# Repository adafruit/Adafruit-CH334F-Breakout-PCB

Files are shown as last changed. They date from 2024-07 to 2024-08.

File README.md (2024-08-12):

## Adafruit CH334F Mini USB Hub Breakouts PCB

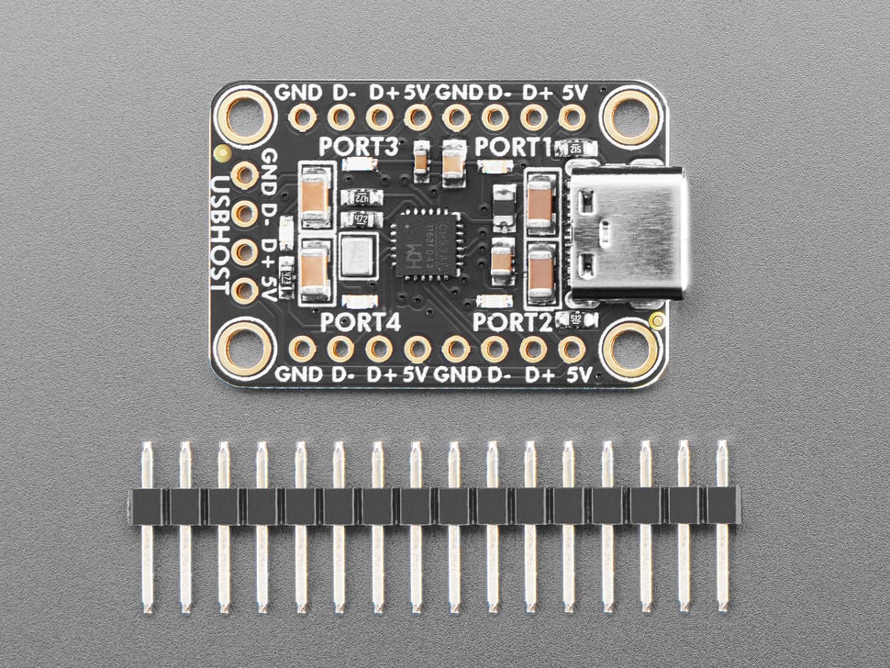
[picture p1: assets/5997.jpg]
<a href="http://www.adafruit.com/products/5997"><br/>
Click here to purchase one from the Adafruit shop</a>
<br>
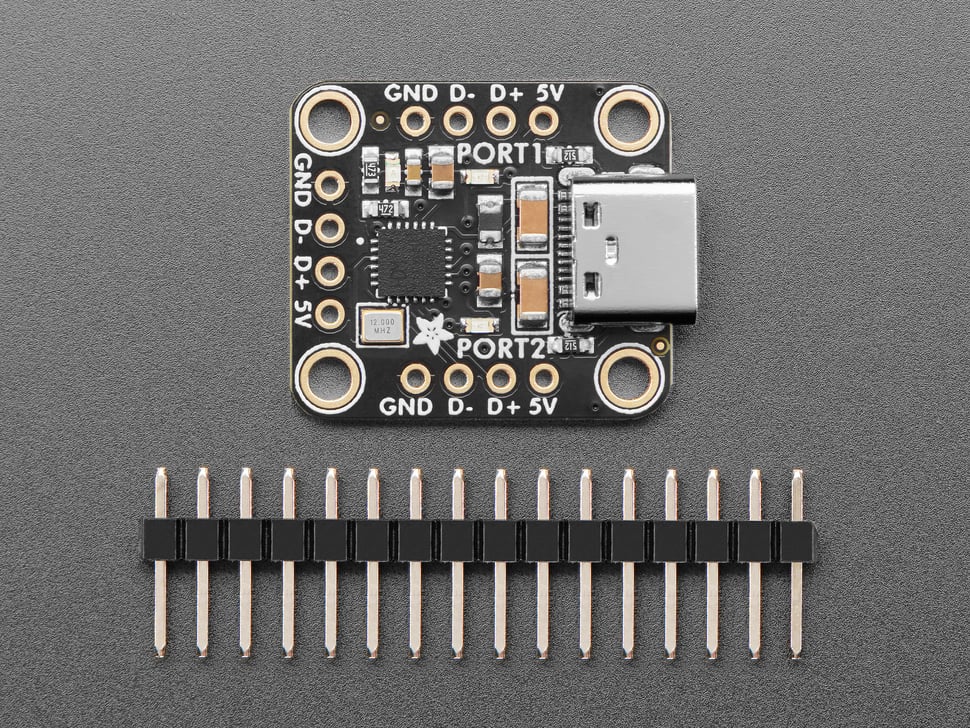
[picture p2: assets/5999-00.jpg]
<a href="http://www.adafruit.com/products/5999"><br/>
Click here to purchase one from the Adafruit shop</a>

PCB files for the Adafruit CH334F Mini USB Hub Breakouts

Format is EagleCAD schematic and board layout
* https://www.adafruit.com/product/5997
* https://www.adafruit.com/product/5999

### Description

Sometimes you've got something with USB host, like a embedded linux board, and you want to connect more than one thing. Or maybe you want to turn something like a keyboard into a multi-device USB peripheral. The Adafruit CH334F Mini 4-Port USB Hub Breakout will do that for you! it features a CH334F USB 2.1 hub chip which converts one high-speed port into four.

Most folks who use a USB hub get one that comes in an enclosure with connectors or cables included. But, those hubs are going to be bulky - they're meant for external use. This breakout board is designed to be compact, so it can easily be embedded into an enclosure or existing device. There's four mounting holes but other than that, we tried to keep it as compact as possible.

Part of how we kept it small is not including downstream ports! The breakout has either 0.1" header or USB C for the upstream, and then four 4-pin ports for peripheral connections. We expect folks to solder directly to the pads or use our 'simple' USB-breakout cables.

You get one fully assembled/tested boards and some extra header if you happen to want to plug it into a breadboard. Other than that, just keep in mind there's no USB ports for the 4 downstreams - if you need those take a look at some of the other hubs we stock.

### License

Adafruit invests time and resources providing this open source design, please support Adafruit and open-source hardware by purchasing products from [Adafruit](https://www.adafruit.com)!

Designed by Limor Fried/Ladyada for Adafruit Industries.

Creative Commons Attribution/Share-Alike, all text above must be included in any redistribution. 
See license.txt for additional details.

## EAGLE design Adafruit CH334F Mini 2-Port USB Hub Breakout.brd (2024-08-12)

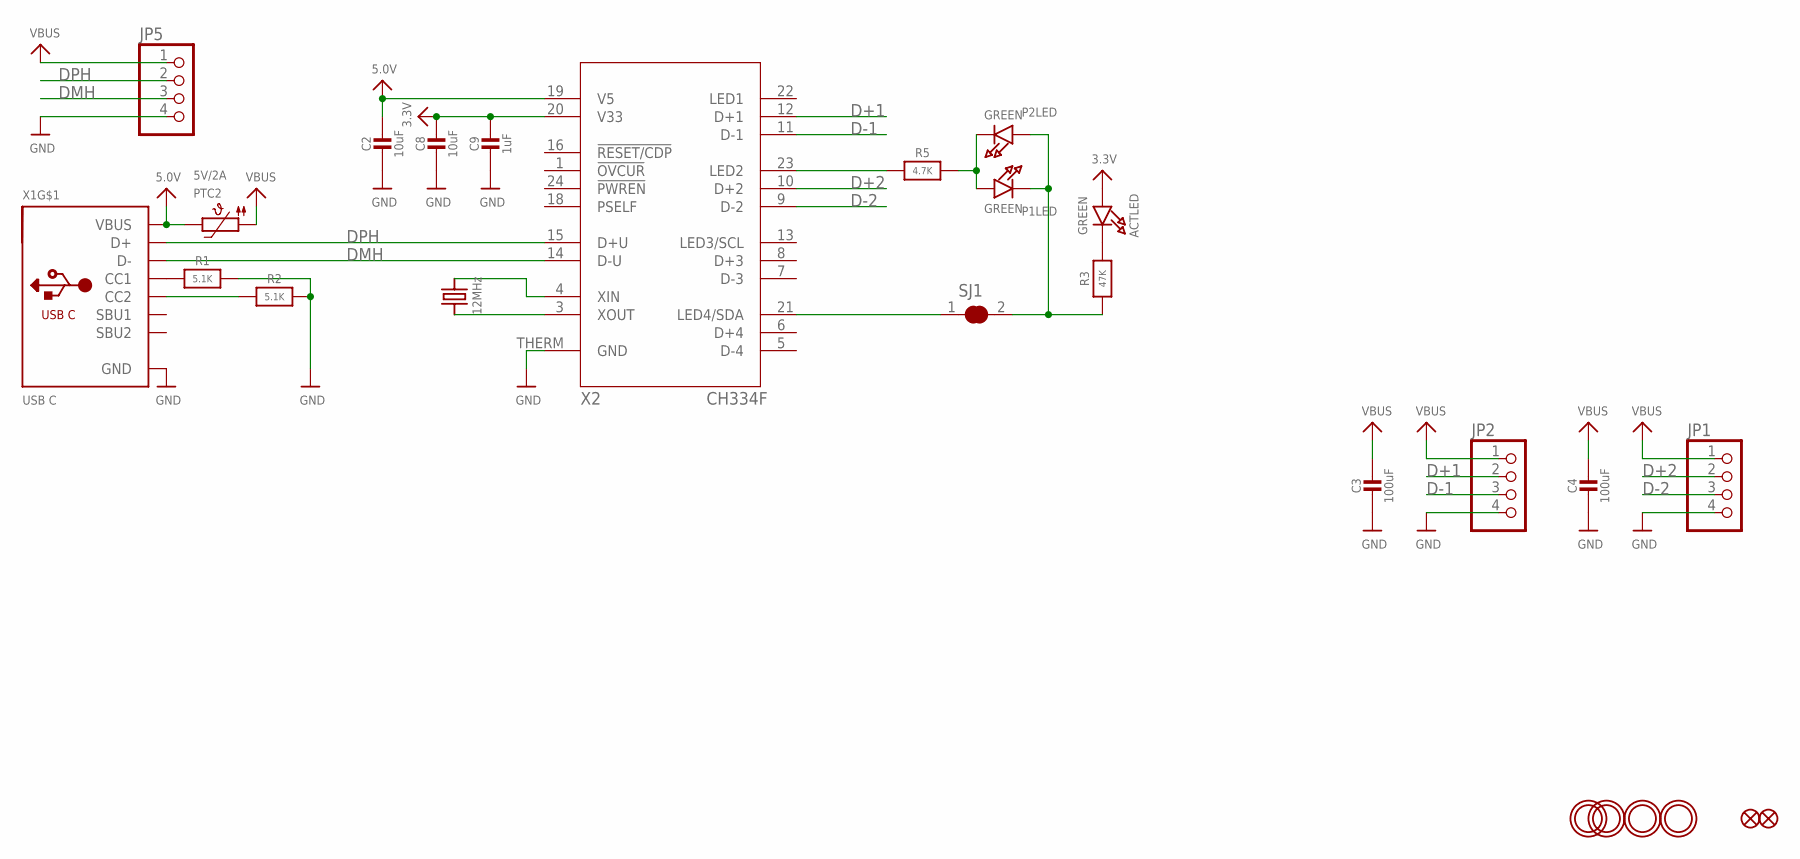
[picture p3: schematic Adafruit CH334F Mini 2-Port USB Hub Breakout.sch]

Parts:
ACTLED: GREEN; CHIPLED_0603_NOOUTLINE
C2, C8: 10uF; 0805-NO
C3, C4: 100uF; _1206
C9: 1uF; 0603-NO
FID1, FID2: FIDUCIAL_0.5MM
JP1, JP2, JP5: HEADER-1X4ROUND; 1X04_ROUND
P1LED, P2LED: GREEN; CHIPLED_0603_NOOUTLINE
PTC2: 5V/2A; 0805-NO
R1, R2: 5.1K; 0603-NO
R3: 47K; 0603-NO
R5: 4.7K; 0603-NO
SJ1: SOLDERJUMPER_CLOSED; SOLDERJUMPER_CLOSEDWIRE
U$23, U$28, U$29, U$31: MOUNTINGHOLE2.5; MOUNTINGHOLE_2.5_PLATED
X1: USB C; USB_C_CUSB31-CFM2AX-01-X
X2: CH334F; QFN24_4MM
Y1: 12MHz; CRYSTAL_2.5X2

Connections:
3.3V: ACTLED.A, C8.1, C9.1, X2.20 (V33)
5.0V: C2.1, PTC2.2, X1.A4B9 (VBUS), X1.B4A9 (VBUS), X2.19 (V5)
D+1: JP2.2, X2.12 (D+1)
D+2: JP1.2, X2.10 (D+2)
D-1: JP2.3, X2.11 (D-1)
D-2: JP1.3, X2.9 (D-2)
DMH: JP5.3, X1.A7 (D-), X1.B7 (D-), X2.14 (D-U)
DPH: JP5.2, X1.A6 (D+), X1.B6 (D+), X2.15 (D+U)
GND: C2.2, C3.2, C4.2, C8.2, C9.2, JP1.4, JP2.4, JP5.4, R1.2, R2.2, X1.A1B12 (GND), X1.B1A12 (GND), X2.THERM (GND)
unnamed: R1.1, X1.A5 (CC1)
unnamed: R2.1, X1.B5 (CC2)
unnamed: X2.3 (XOUT), Y1.1
unnamed: X2.4 (XIN), Y1.3 (2)
unnamed: ACTLED.C, R3.2
unnamed: P1LED.C, P2LED.A, R3.1, SJ1.2
unnamed: SJ1.1, X2.21 (LED4/SDA)
unnamed: P1LED.A, P2LED.C, R5.2
unnamed: R5.1, X2.23 (LED2)
VBUS: C3.1, C4.1, JP1.1, JP2.1, JP5.1, PTC2.1

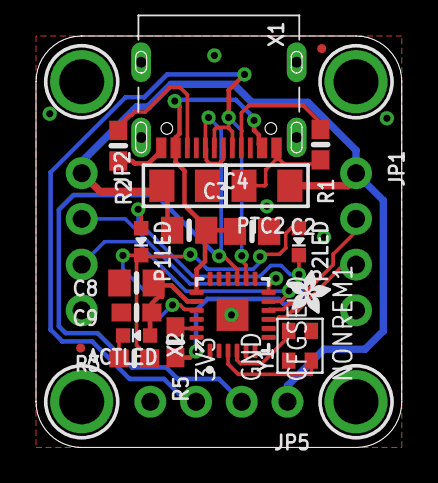
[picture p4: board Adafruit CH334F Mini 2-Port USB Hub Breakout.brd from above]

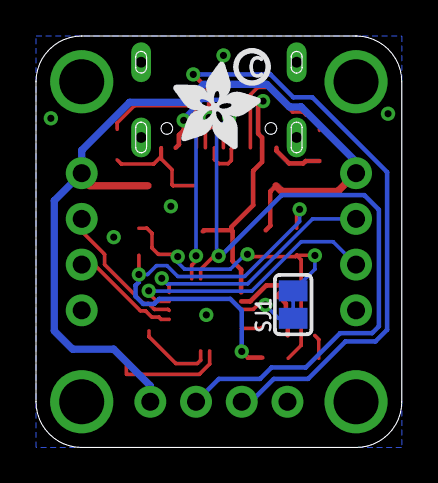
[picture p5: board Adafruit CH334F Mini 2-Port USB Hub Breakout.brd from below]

Board: 2 copper layers, 20.3 x 22.9 mm, 49 parts (9 on the bottom side), 19 nets.

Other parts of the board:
PLABEL0: PLABEL0
PLABEL1: PLABEL1
PLABEL3: PLABEL3
PLABEL5: PLABEL5
PLABEL6: PLABEL6
PLABEL7: PLABEL7
PLABEL8: PLABEL8
PLABEL11: PLABEL11
PLABEL13: PLABEL13
PLABEL19: PLABEL19
PLABEL21: PLABEL21
PLABEL22: PLABEL22
PLABEL23: PLABEL23
PLABEL24: PLABEL24
PLABEL26: PLABEL26
PLABEL27: PLABEL27
PLABEL30: PLABEL30
PLABEL31: PLABEL31
PLABEL32: PLABEL32
PLABEL33: PLABEL33
U$11: ADAFRUIT_2.5MM
U$33: ADAFRUIT_5MM
U$34: PCBFEAT-REV-040

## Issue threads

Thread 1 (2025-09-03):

Silkscreen error on port labels

BryceKarlins, 2025-09-03:
Note: The downstream port numbers on the top of the board are inconsistent with the labels on the bottom of the board. This isn't really something that should ever cause a functional issue, but was a bit disconcerting.

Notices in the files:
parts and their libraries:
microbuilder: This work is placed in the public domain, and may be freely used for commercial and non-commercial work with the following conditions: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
